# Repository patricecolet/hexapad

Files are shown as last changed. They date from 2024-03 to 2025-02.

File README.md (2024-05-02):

# HEXAPAD
MIDI USB hexagonal interface made of 7 pads with velocity, aftertouch, and and a distance sensor

### [- Introduction](#Introduction)
### [- Description](#Description)
### [- Schematique](#Schematique)
### [- PCB](#PCB)
### [- Firmware](#Firmware)
### [- Dependences](#Dependences)
### [- MIDI implementation](#implementation)
  
### Introduction

Cet appareil est un hexapad doté de différents capteurs capacitifs qui, lorsqu'ils sont en contract avec des doigts, envoient des signaux ou commandes MIDI à l'aide d'un câble USB vers un ordinateur.
Le MIDI est est un protocole de communication et un format de fichier dédiés à la musique utilisés pour la communication entre instruments électroniques, contrôleurs, séquenceurs, et logiciels de musique.
 
Le microcontrôleur utilisé est un Seeed Studio XIAO SAMD21 qui est programmé avec l'IDE Arduino. Il dispose de 7 entrées capacitives Qtouch qui servent à déclencher des notes de musique, d'un capteur de vibrations piézoélectriques et d'un capteur de proximité infrarouge pour modifier les sons. 

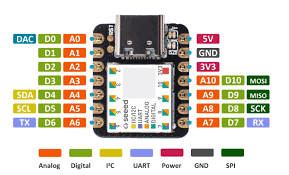
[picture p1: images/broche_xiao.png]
Seeeduino broche


### Description

Nous disposons de 7 broches pour nos capteurs capacitifs qui doivent etre répartie avec la meme surface.

L'idée serait donc une forme hexagonale qui serait divisée en 6 parties, avec un hexagone plus petit au centre.

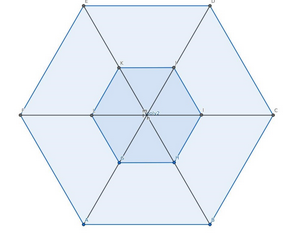
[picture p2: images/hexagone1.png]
hexagone prototype


L'hexagone devra faire 15,5 cm de haut et chaque trapèse doit etre espacé de 2 mm pour éviter les perturbations. C'est a l'aide du logiciel Geogebra que nous avons réussi a trouver les dimensions idéale.

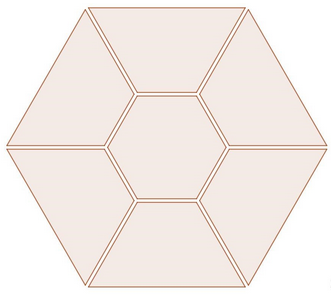
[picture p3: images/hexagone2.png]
hexagone final


### SCHEMATIQUE 

Voici l'élaborer de la carte électronique qui accueillera nos capteurs capacitifs, le microcontrôleur, le capteur de vibration et le capteur de distance.

Conformément aux recommandations de la documentation technique, nous avons mis en place des résistances de Pull Up  sur chaque broche du capteur de distance (VL53l0X) et nous avons mis des condensateurs de découplage sur AVDD et AVDDVCSEL.

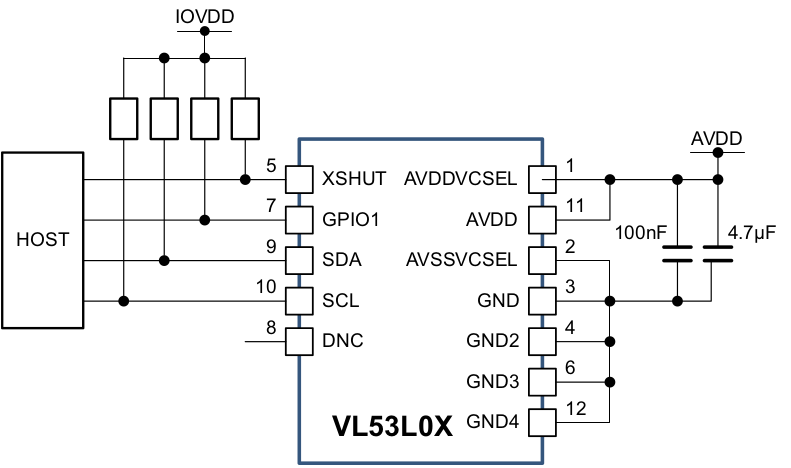
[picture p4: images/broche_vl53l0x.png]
data sheet VL53L0X


Nous avons également installé des boutons poussoir pour réinitialiser le microcontrôleur et le VL53L0X. Enfin pour le câblage du piezo, nous avons mis une résistance et une diode en parallèle. 

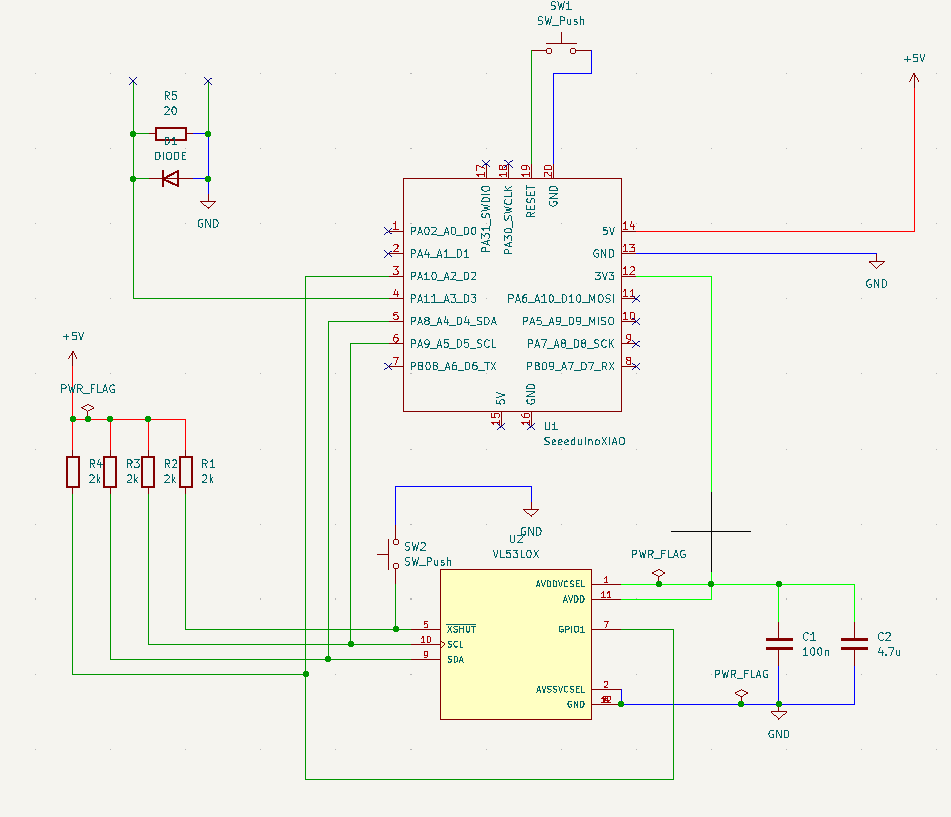
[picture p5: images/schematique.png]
Schematique final


### PCB 

Pour la partie PCB, les composants devaient etre tous groupés pour que la carte ne soit pas trop grande.

Des tests ont étés réalisé aux préalables pour savoir si la longueur des fils/pistes pouvait avoir une influence sur la sensibilité des capteurs. En réalité, plus les pistes sont étendues, plus la variation du signal est faible. C'est pour cette raison que nous devons nous assurer que les pistes soient les moins longues possibles.

Pour éviter toute perturbation, l'hexagone sera recouvert d'un plan de masse qui nous protègera des parasites.

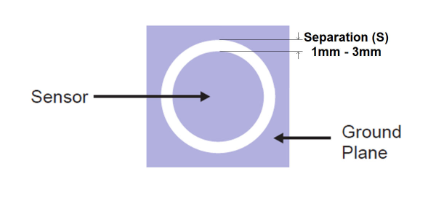
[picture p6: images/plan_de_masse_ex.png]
Exemple plan de masse


De ce fait il y a moins de charges capacitives entre chaque capteur car elles sont entraînées vers le même potentiel. Il y aura un champ électrique plus fort entre le capteur et l'utilisateur, ce qui augmentera la sensibilité des capteurs.

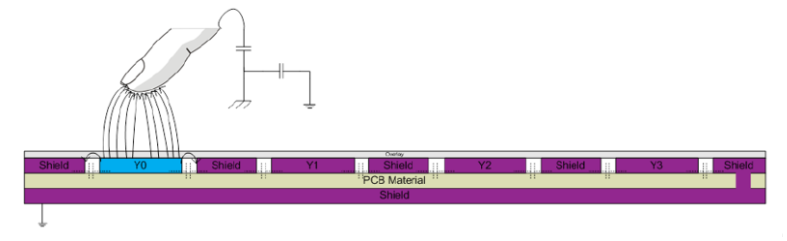
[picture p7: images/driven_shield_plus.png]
Shield


### Firmware

Le programme est composé de 4 grandes parties :

#### [-Capteur de distance](#distance)
#### [-Capteur Piezoelectrique](#Piezoelectrique)
#### [-Capteur capacitif Qtouch](#Qtouch)
#### [-Message Midi](#Midi)

##### Capteur de distance 

##### Capteur Piezoelectrique

Le capteur piézoélectrique est un capteur de vibration, il va donc nous permettre de détecter l'intensité de nos appuis sur l'hexapad. Nous allons utiliser la fonction TimerCallBack pour faire appel à notre capteur piézo lorsqu'il détectera un changement d'état de sa part. Nous avons choisi de structurer le code du piézo en utilisant un Switch case pour évaluer l'état de notre piezo.

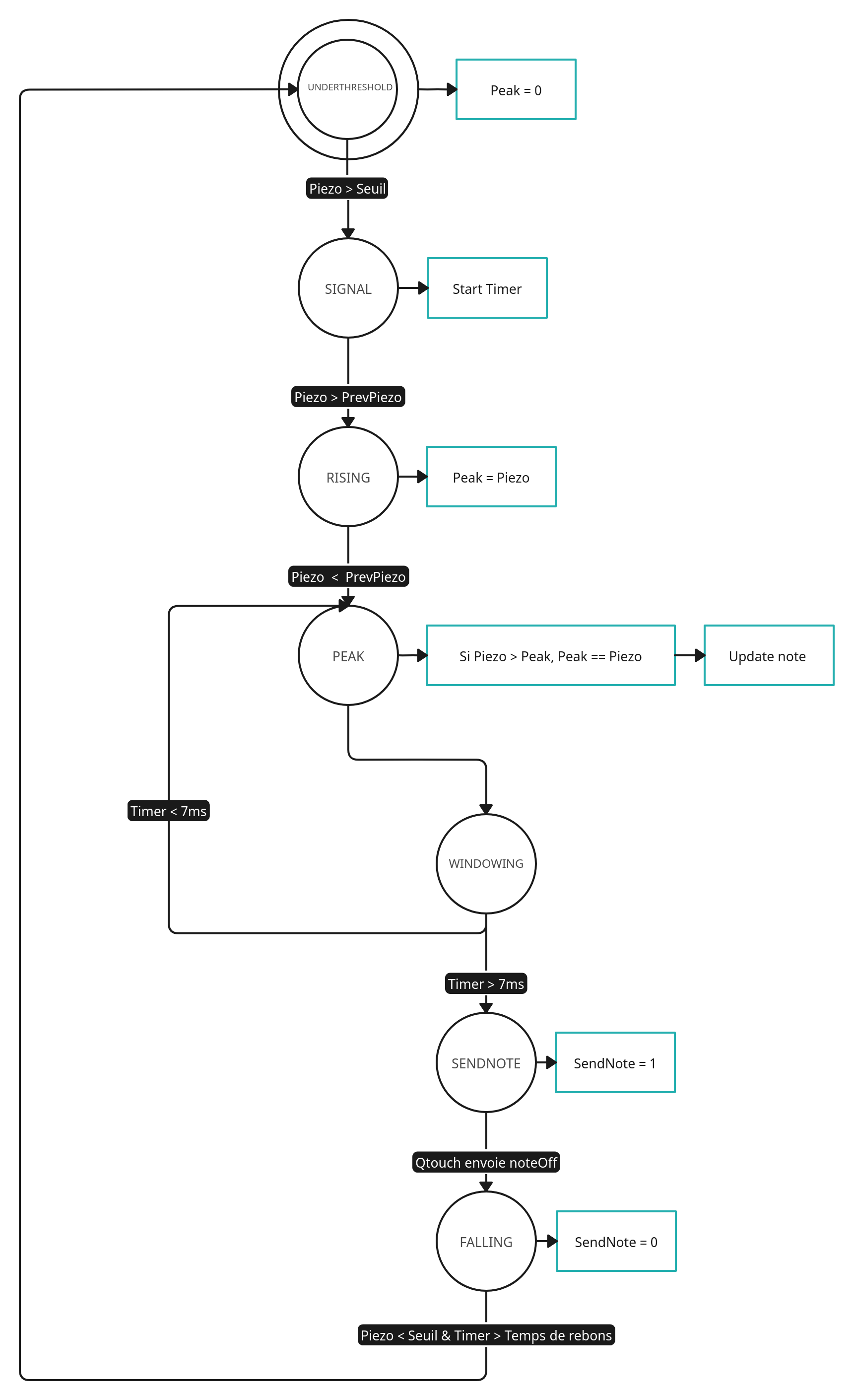
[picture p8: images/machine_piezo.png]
Machine_Piezo


Les doubles rebonds persistaient toujours donc nous avons implanter un seuil glissant qui varirait en fonction de la valeur peak du piézo.

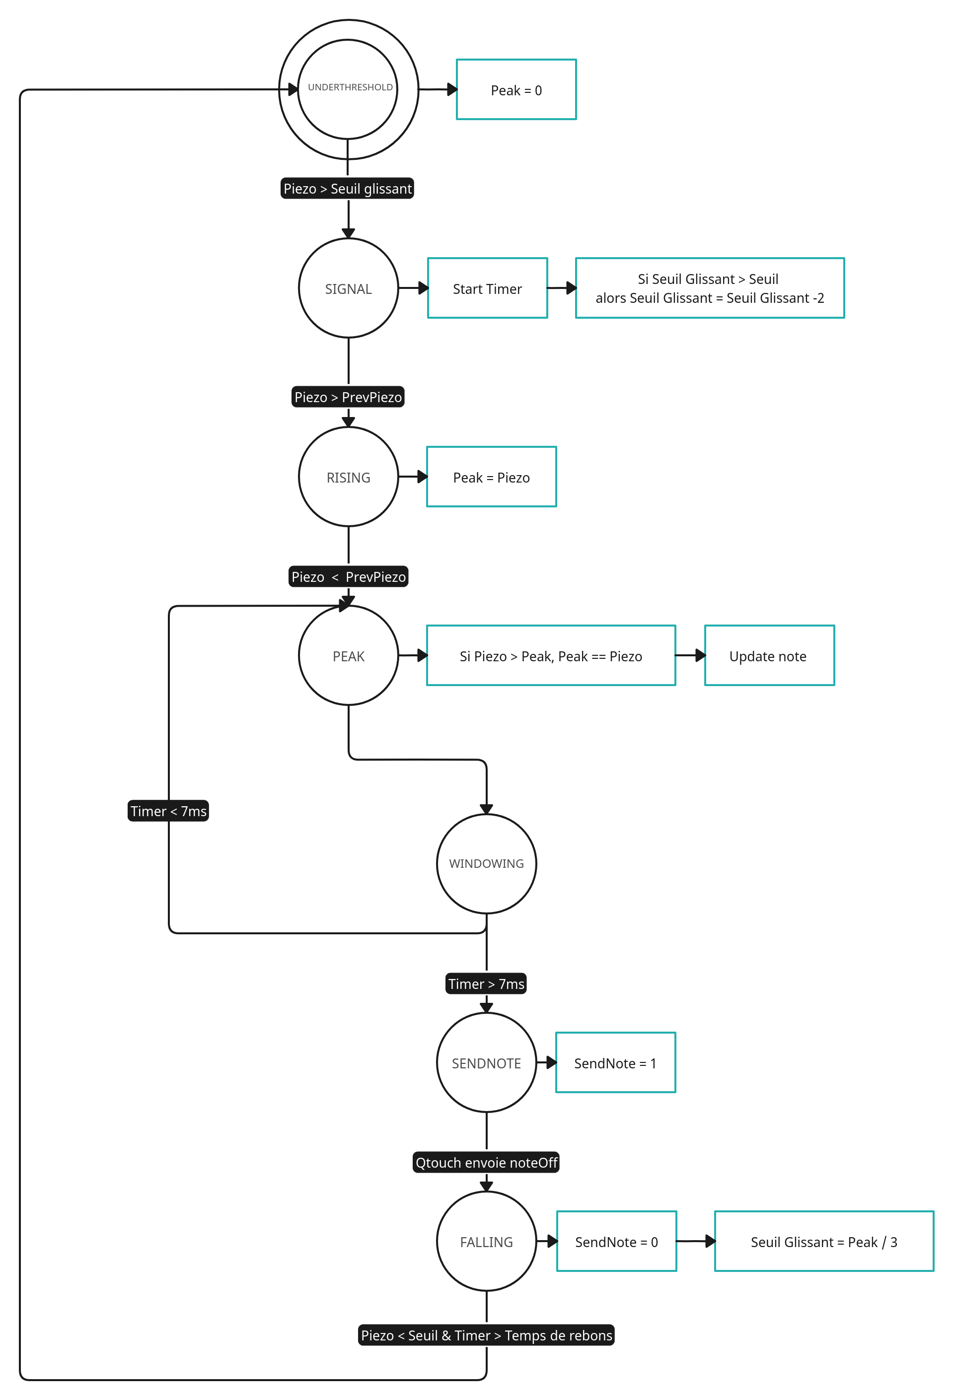
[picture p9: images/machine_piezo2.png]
Machine_Piezo2


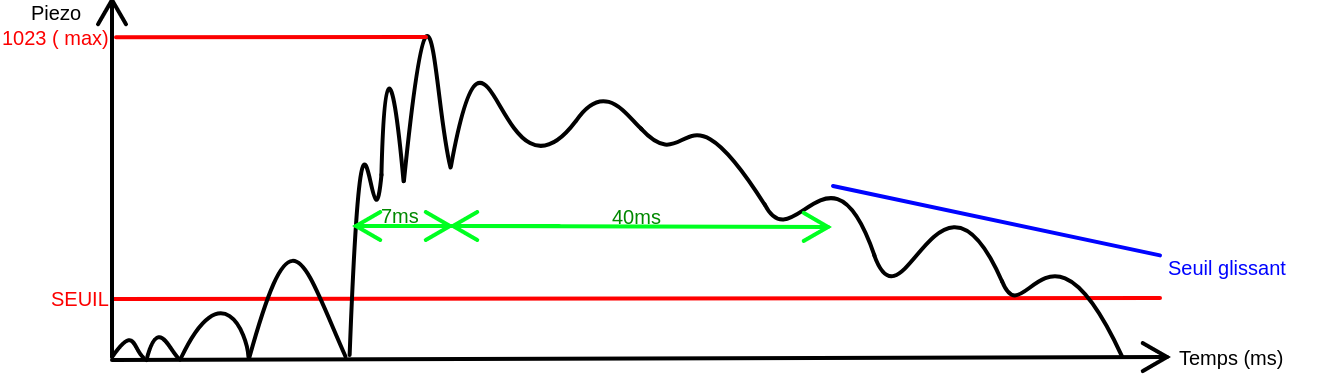
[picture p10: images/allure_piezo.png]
Allure_Piezo


##### Capteur capacitif Qtouch

Les hexapad se déclanche lorsqu'un doigt s'approche d'un capteur capacitif, il va perturbe le champ électrique du pad, ce qui est détecté par l'entrée QTouch. Cela permet au microcontroller de déterminer la surface du toucher et va intéragir avec du son plus ou moins déformer. On va nommé cette deformation l'AfterTouch.

##### Message Midi

## Dependences

* MIDIUSB
* Adafruit_FreeTouch
* Adafruit_VL53L0X
* MovingAverage

## MIDI implémentation

* Canal 1 -> Pad 1
* Canal 2 -> Pad 2
* Canal 3 -> Pad 3
* Canal 4 -> Pad 4
* Canal 5 -> Pad 5
* Canal 6 -> Pad 6
* Canal 7 -> Pad 7
* Canal 8 -> Lidar
* Canal 9 -> Advanced Settings

|STRUCTURE MESSAGE SYSEX| Description|
|---|---|
|F0|Début du message Sysex|
|H|Identifiant|
|E|Identifiant|
|X|Identifiant|
|A|Identifiant|
|P|Identifiant|
|A|Identifiant|
|0|Fin Identifiant|
|1(SET) ou 2(GET)|Commande|
|1|Version|
|0|Révision|
|XX|Channel|
|XX|Numéro de paramètre|
|XX|Value|
|F7|Fin du message Sysex|

|NUMERO DE PARAMETRE|PADSETTINGS|
|---|---|
|1|Channel|
|2|Note 1|
|3|Seuil 1|
|4|Identifiant|
|5|Identifiant|
|6|Identifiant|
|7|Identifiant|
|8|Fin Identifiant|
|9(SET) ou 2(GET)|Commande|
|1|Version|
|0|Révision|
|XX|Channel|
|XX|Numéro de paramètre|
|XX|Value|
|F7|Fin du message Sysex|

#TODO

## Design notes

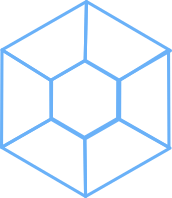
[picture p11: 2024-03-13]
hexapad.png

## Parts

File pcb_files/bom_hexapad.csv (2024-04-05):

Id | Designator | Package | Quantity | Designation | Supplier and ref
1 | U2 | SENSOR_VL53L0X | 1 | VL53L0X
2 | R3,R2,R4,R1 | R_0805_2012Metric | 4 | 2K
3 | R5 | R_0805_2012Metric | 1 | 20K
4 | C2 | C_Elec_4x5.4 | 1 | 4.7uF
5 | SW2,SW1 | SW_Push_1P1T_NO_6x6mm_H9.5mm | 2 | SW_Push
6 | D1 | D_SOD-323 | 1 | DIODE
7 | C1 | C_0402_1005Metric | 1 | 100nF
8 | U1 | Seeeduino XIAO-MOUDLE14P-2.54-21X17.8MM | 1 | SeeeduinoXIAO

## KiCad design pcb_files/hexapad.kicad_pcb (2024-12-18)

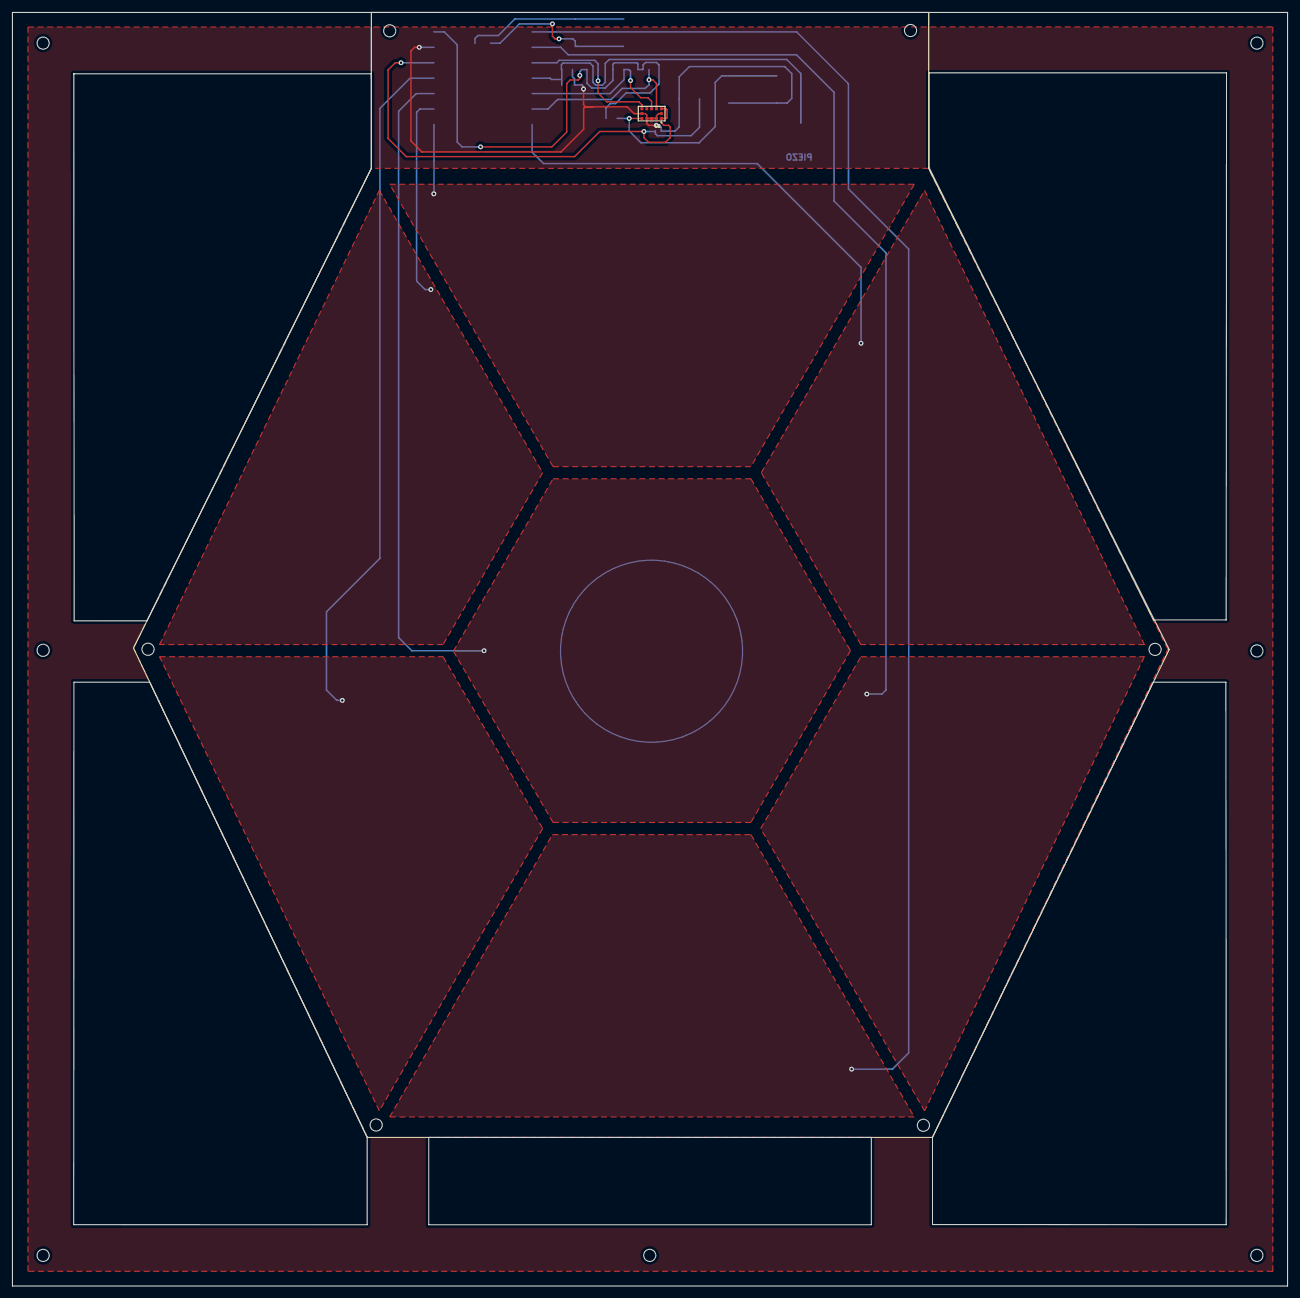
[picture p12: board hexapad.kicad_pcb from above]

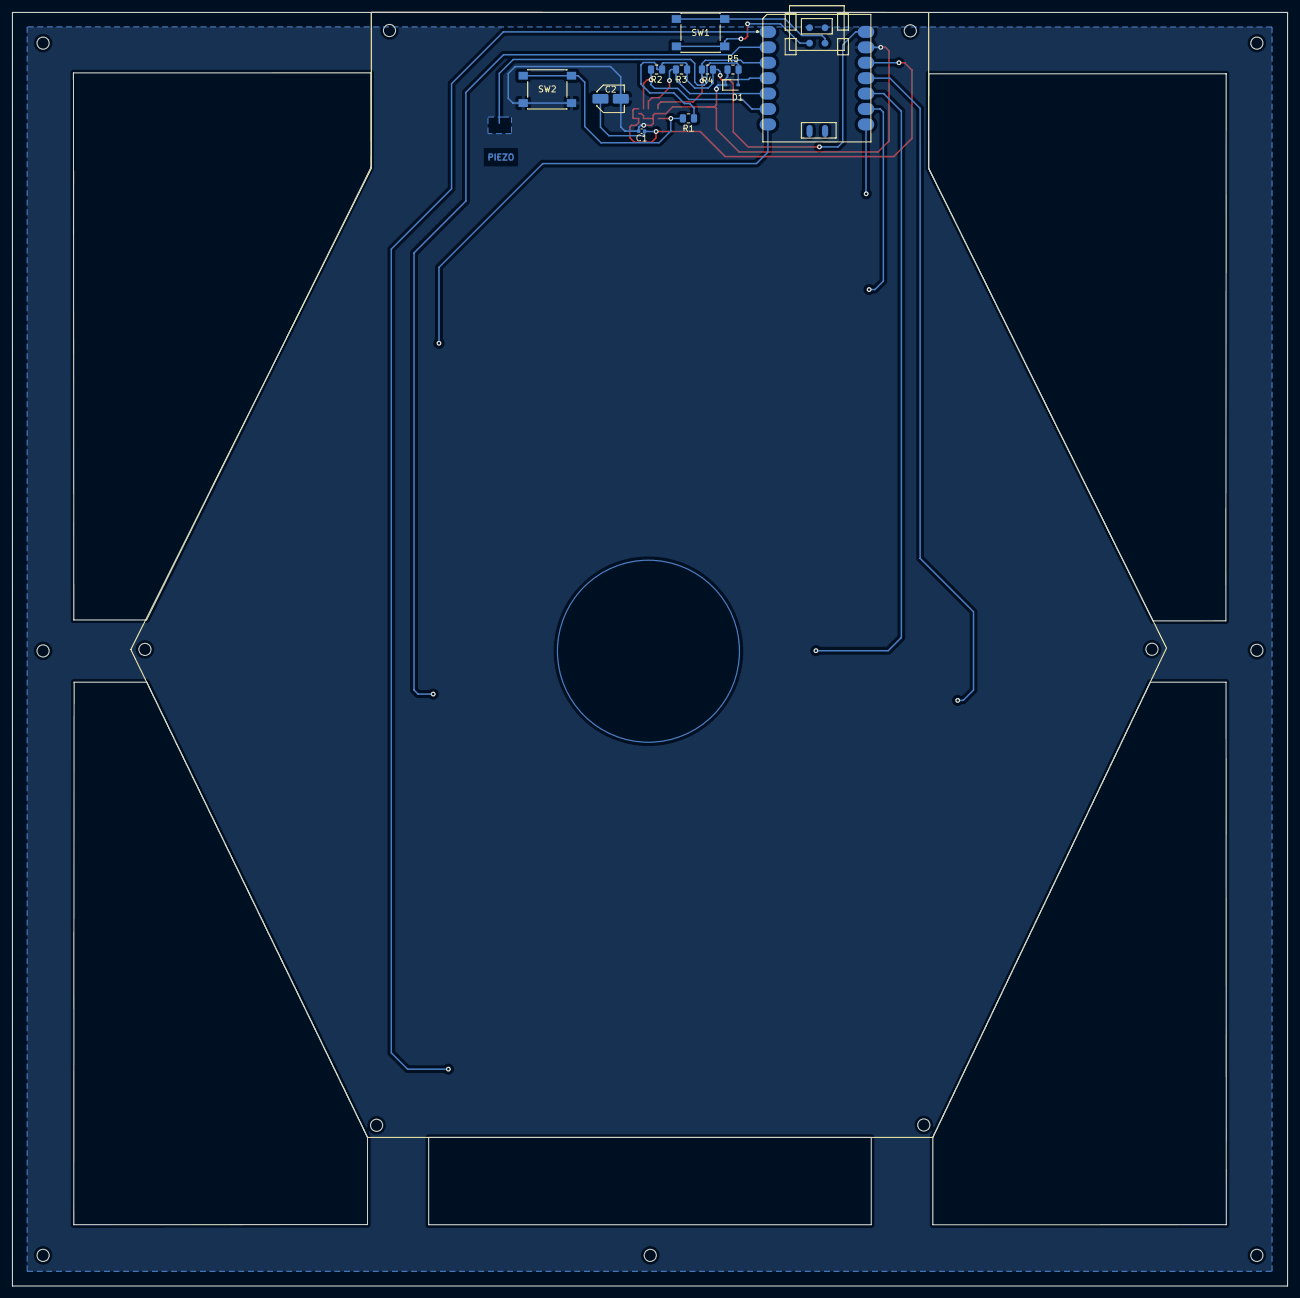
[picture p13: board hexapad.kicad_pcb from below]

Board: 2 copper layers, 210.0 x 209.7 mm, 12 parts (11 on the bottom side), 9 nets.

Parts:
C1: 100nF; C_0402_1005Metric
C2: 4.7uF; C_Elec_4x5.4
D1: DIODE; D_SOD-323
R1, R2, R3, R4: 2K; R_0805_2012Metric
R5: 20K; R_0805_2012Metric
SW1, SW2: SW_Push; SW_Push_1P1T_NO_6x6mm_H9.5mm
U1: SeeeduinoXIAO; Seeeduino XIAO-MOUDLE14P-2.54-21X17.8MM
U2: VL53L0X; SENSOR_VL53L0X

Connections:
+5V: R1.1, R2.1, R3.1, R4.1, U1.14 (5V)
GND: C1.2, C2.2, D1.1 (A), R5.2, SW2.2, U1.13 (GND), U2.2 (AVSSVCSEL), U2.3 (GND), U2.4 (GND), U2.6 (GND), U2.12 (GND)
unnamed: C1.1, C2.1, U1.12 (3V3), U2.1 (AVDDVCSEL), U2.11 (AVDD)
unnamed: R1.2, SW2.1, U2.5 (~XSHUT)
unnamed: R2.2, U1.6 (PA9_A5_D5_SCL), U2.10 (SCL)
unnamed: R3.2, U1.5 (PA8_A4_D4_SDA), U2.9 (SDA)
unnamed: R4.2, U1.3 (PA10_A2_D2), U2.7 (GPIO1)
unnamed: SW1.1, U1.19 (RESET)
unnamed: SW1.2, U1.20 (GND)

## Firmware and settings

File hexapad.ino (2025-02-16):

#include "hexapad.h"

void setup() {
  Serial.begin(9600);
  delay(2000); 
  Serial.println("HEXAPAD SETUP");
  qTouchBegin();
  delay(1000);   
  qTouchCalibrate();
  delay(1000);  
  pinMode(VL53LOX_InterruptPin, INPUT_PULLUP);
/*  if (!Distance.begin()) {
    Serial.println(F("Failed to boot VL53L0X"));
    delay(100);
  }
  */
  timerPBegin();
  MidiMessage.begin();

}

void loop() {
  qTouchUpdate();
  MidiMessage.update();
  // MidiMessage.midiInMessages();
}

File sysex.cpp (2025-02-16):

#include "sysex.hpp"

midiMessage _MIDI;

byte padSettingsBytes[sizeof(PadSettings) * 7 + 2];
byte advancedSettingsBytes[sizeof(AdvancedSettings) + 2];

// class sysex constructor
sysex::sysex(){
};

// callback function trigged when a sysex packet is received
void sysex::parse(byte * data, unsigned length){
  for (int i = 0; i < length; i++) Serial.println(data[i]);

  if ((data[0] == 240) && (data[length - 1] == 247) && length > 2) { // check sysex packet
    if(checkID(data) == 1) {                                         // check sysex ID (should be "HEXAPAD1")
      if (data[9] == (byte)sysexCommand::set) set(data);             // command 'set' = 0x1
      if (data[9] == (byte)sysexCommand::get) dump(data);             // command 'get' = 0x2
      if (data[9] == (byte)sysexCommand::calibrate) calibrate();     // command 'calibrate' = 0x3
    }
    else Serial.println("wrong sysex ID");
  }
}
bool sysex::checkID (byte * data) {
  bool status = 1;
  for (int i = 0; i < 8; i++) if(data[i+1] != SysexID[i]) status ==  0;
  return status;
}

void sysex::calibrate() {
  
}
// sysex command to set parameter
void sysex::set(byte * data) {
  if((data[10] == 1) && (data[11] == 0)) {                            // version 1 & revision 0 of set command
    switch (data[12]) {                                               // set target
      case (byte)hexapad::pad1 : pad((byte)hexapad::pad1,data);break;
      case (byte)hexapad::pad2 : pad((byte)hexapad::pad2,data);break;
      case (byte)hexapad::pad3 : pad((byte)hexapad::pad3,data);break;
      case (byte)hexapad::pad4 : pad((byte)hexapad::pad4,data);break;
      case (byte)hexapad::pad5 : pad((byte)hexapad::pad5,data);break;
      case (byte)hexapad::pad6 : pad((byte)hexapad::pad6,data);break;
      case (byte)hexapad::pad7 : pad((byte)hexapad::pad7,data);break;
      case (byte)hexapad::lidar : lidar(data);break;
      case (byte)hexapad::advanced : advanced(data);break;
      default: break;
    }
    Serial.print("target: ");
    Serial.println(data[12]);
  }
};

// update pad parameter state
void sysex::pad(byte pad, byte * data) {
  byte param = data[13];
  byte value = data[14];
  byte value2 = data[15];
  switch (param) {
    case (byte)padParam::channel : padSettings[pad].channel = value;break;
    case (byte)padParam::note : padSettings[pad].note = value;break;
    case (byte)padParam::trig_mode : padSettings[pad].trig_mode = (trigType)value;break;
    case (byte)padParam::velocity_curve : padSettings[pad].velocity_curve = (curveType)value;break;
    case (byte)padParam::aftertouch_curve : padSettings[pad].aftertouch_curve = (curveType)value;break;
    case (byte)padParam::piezo : padSettings[pad].piezo = value;break;
    case (byte)padParam::qtouch : padSettings[pad].qtouch = value;break;
    case (byte)padParam::qtouch_onset : padSettings[pad].qtouch_onset = (value << 7) | value2;break;
    case (byte)padParam::qtouch_offset : padSettings[pad].qtouch_offset = (value << 7) | value2;break;
    case (byte)padParam::qtouch_ceiling : padSettings[pad].qtouch_ceiling = (value << 7) | value2;break;
    default: break;
  }
}

// update lidar parameter state
void sysex::lidar(byte * data) {
  byte param = data[13];
  byte value = data[14];
  switch (param) {
    case (byte)lidarParam::channel : Lidar.channel = value;break;
    case (byte)lidarParam::note : Lidar.note = value;break;
    case (byte)lidarParam::curve : Lidar.curve = (curveType)value;break;
    case (byte)lidarParam::lowThresholdLSB : Lidar.lowThresholdLSB = value;break;
    case (byte)lidarParam::lowThresholdMSB : Lidar.lowThresholdMSB = value;break;
    case (byte)lidarParam::highThresholdLSB : Lidar.highThresholdLSB = value;break;
    case (byte)lidarParam::highThresholdMSB : Lidar.highThresholdMSB = value;break;
    case (byte)lidarParam::controllerLSB : Lidar.controllerLSB = value;break;
    case (byte)lidarParam::controllerMSB : Lidar.controllerMSB = value;break;
    case (byte)lidarParam::enable : Lidar.enable = value;break;
    default: break;
  } 
}
// update advanced parameter state
void sysex::advanced(byte * data) {
  byte param = data[13];
  byte value = data[14];
  switch (param) {
    case (byte)advancedParam::piezoThresholdLSB : advancedSettings.piezoThresholdLSB = value;break;
    case (byte)advancedParam::piezoThresholdMSB : advancedSettings.piezoThresholdMSB = value;break;
    case (byte)advancedParam::piezoSensitivityLSB : advancedSettings.piezoSensitivityLSB = value;break;
    case (byte)advancedParam::piezoSensitivityMSB : advancedSettings.piezoSensitivityMSB = value;break;
    case (byte)advancedParam::piezoDebounceTimeLSB : advancedSettings.piezoDebounceTimeLSB = value;break;
    case (byte)advancedParam::piezoDebounceTimeMSB : advancedSettings.piezoDebounceTimeMSB = value;break;
    case (byte)advancedParam::qtouchRoundOff : advancedSettings.qtouchRoundOff = value;break;
    default: break;
  }   
}

// sysex command to set parameter
void sysex::dump(byte * data) {

  if((data[10] == 1) && (data[11] == 0)) {  // version 1 & revision 0 of get command
    for (int i=0; i<7; i++) {
      int length = 25;
      byte message [length] = {};
      for (int i=0; i<9; i++) message[i]=data[i];
      message[9]=(byte)sysexParam::pad;         
      message[10]=i;
      message[11]=padSettings[i].channel;
      message[12]=padSettings[i].note;
      message[13]=(byte)padSettings[i].trig_mode;
      message[14]=(byte)padSettings[i].velocity_curve;
      message[15]=(byte)padSettings[i].aftertouch_curve;
      message[16]=padSettings[i].piezo;
      message[17]=padSettings[i].qtouch;
      message[18]=(padSettings[i].qtouch_onset >> 7) & 0x7F;
      message[19]=padSettings[i].qtouch_onset & 0x7F;
      message[20]=(padSettings[i].qtouch_offset >> 7) & 0x7F;
      message[21]=padSettings[i].qtouch_offset & 0x7F;
      message[22]=(padSettings[i].qtouch_ceiling >> 7) & 0x7F;
      message[23]=padSettings[i].qtouch_ceiling & 0x7F;
      message[24]=0xF7;
      _MIDI.sysexSend(message, length);
    }           
  }
}

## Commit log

2024-03-22 mode button bool
2024-03-22 mode button fonctionelle sans aftertouch
2024-03-29 Update README.md
    midi implémentation todo et dépendances à la fin du README et ajoutés au sommaire
2024-04-05 kicad pd projet
    [bom_hexapad.csv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]
2024-04-08 probleme velocity
2024-04-09 nouvelle velocity et debug
2024-04-11 removed sendNote from piezo class, added debug level, velocity doesn't go to previous value anymore
    [hexapad.ino, midimap.h, piezo.cpp]
2024-04-15 reglage pb velocity
2024-04-16 renamed hexapad to pcb_files, added jsfx editor file
    [bom_hexapad.csv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]
2024-04-17 suppression d un dosssier en doublon
    [bom_hexapad.csv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]
2024-04-17 reglage debounce time et debut de l'implémentation du controller 0
2024-04-18 implementation de l'envoie du buffer
2024-04-18 mise en place du DEBUG pour les messages dans midimessage
2024-04-19 Premier test de la mise en place des differente note selon le qtouch et modification du ReadMe
2024-04-19 supression de la 4eme note
2024-04-19 correction code + debut developpement Readme
    [midimap.h, midimessage.cpp]
2024-04-26 commencement implémentation du capteur de distance dans midimessage
2024-04-29 ajout mode button et mode Keyboard sur le capteur de distance
2024-04-29 deplacement de AfterTouchNote et VelocityCurve de Midimessage a Hexapad.h
2024-05-02 Structure des messages Sysex
2024-12-18 update pcb and sysex
    [hexapad.kicad_pcb]
